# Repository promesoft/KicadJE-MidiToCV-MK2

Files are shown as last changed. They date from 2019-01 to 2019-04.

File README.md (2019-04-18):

# Kicad-MidiToCV
Midi to CV in Eurorack 

# MK2 Design 
## Status - PCB delivered tested
## Initial 
| Stage  | Detail | Status |
| --- | --- | --- |
| create material  | sch/pcb | produced MK2 Rev A  |
| | gerber | Produced MK2 |
| production  | ordered  |  |
|  | produced | yes |
|  | delivered | yes |
## Preliminary validation
| Test  | Detail | Status |
| --- | --- | --- |
| Initial Inspection | conflict between LED on front panel and optional CV7 | OK |
| Initial Technical Test | | OK |
| Initial Product Test |  | OK! |
|  | LED's | OK |
|  | Encoder | OK |
|  | CV1+CV2 | OK |
|  | GATE 1,2,3,4 | OK |
|  | MIDI I/O | OK |

## Secondary validation
| Test  | Detail | Status |
| --- | --- |--- |
| Product Test |  | |
| Quality |  | |
| Long Term Product Test | | Mounted in rack |

## Software 
| Test  | Detail | Status |
| --- | --- |--- |
| Initial SW | copy from MK1 and adjusted | OK! |
| MIDI I/O | UI | |
| MIDI I/O | Filtering and change ch | |
| CV Control | UI |  |
| CV Control | |  |
| LFO Control | UI |  |
| LFO Control | Function |  |

## Errata
 * Physical mounting of the faceplate to holes on the base plate requires other dimensions of the angled mounts. The mounts can be very difficult to get in place due to limited space behind the front PCB.
## Issues and Notes
 * Note - the 4 value LED's are routed across the front board next to analogue and gate signals - so care should be taken when deciding between constant power or PWM control of brightness. The other LED's are not considered as vital as they will normally be lit when config is changed.
 * Consider replacing single row board connector with double row.
 * Physical construction not finalized
### Workarounds

## Base Construction
### Arduino base board 
 - Arduino Nano
 - MIDI IN/OUT connectors
 - CV 1 and CV 2 as Mini Jacks (PJ-301) with variable x2-x3 amplification and 1st order LP filter
 - Gate 1 and Gate 2 as Mini Jacks (PJ-301) 5V
 - Gate 3 and Gate 4 as Mini Jacks (PJ-321) with fixed x2 amplification and sallen-key LP 2nd order filter
 - Board connector 9pin and 11pin from base board to front board
 - 16pin Europower connector
 - Barreljack for 7-12V digital Pwr
 
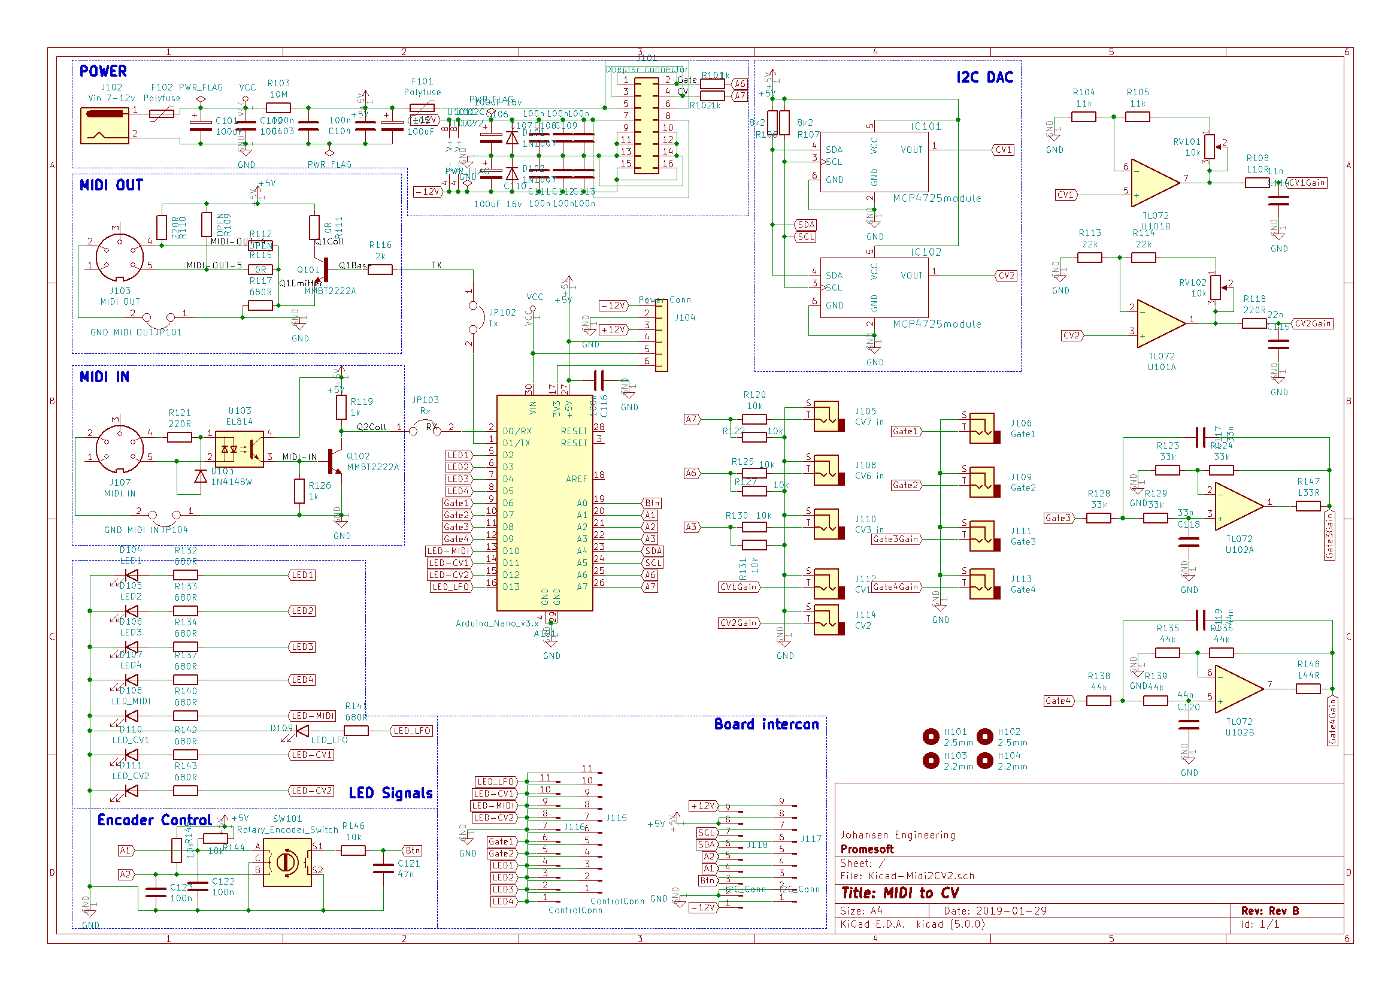
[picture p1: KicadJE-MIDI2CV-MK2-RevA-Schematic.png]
 
 
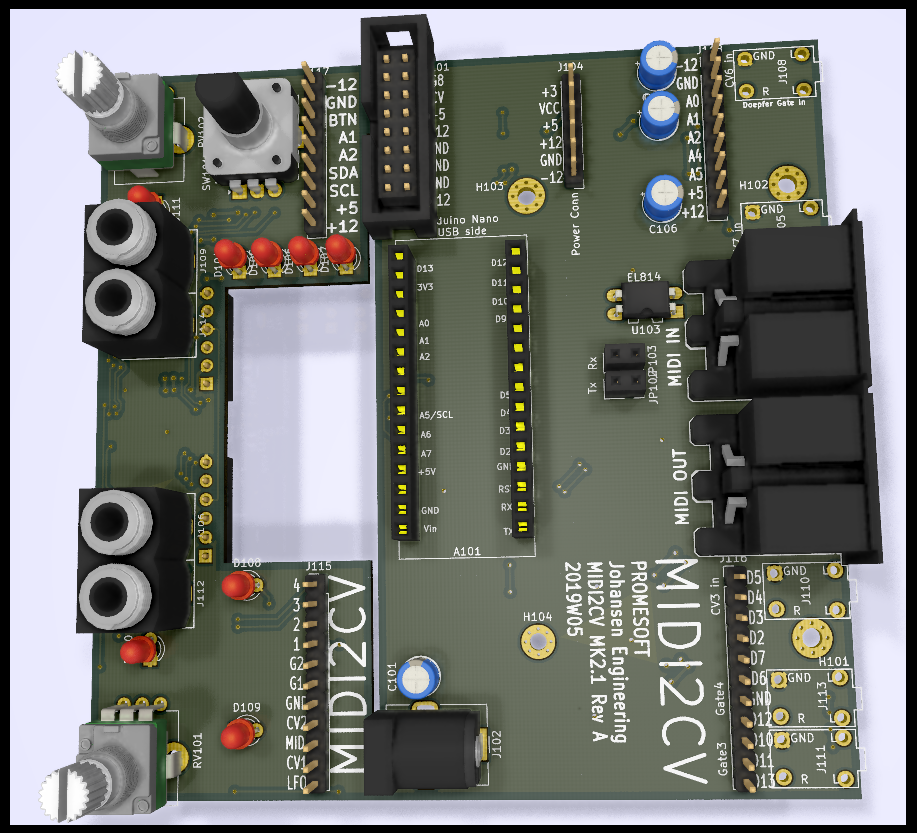
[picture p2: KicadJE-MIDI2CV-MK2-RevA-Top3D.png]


## Vital Components
 - Arduino Nano - where the magic lives (remember to socket it to be able to reprogram it - two jumpers are in place for Rx/Tx so socket may be avoided)
 - Jack connectors: PJ-321 for the base board and PJ-301 for the front board (important for the footprint)
 - ALPS EC-11 Encoder (important for the footprint and 3D alignment)
 - ALPS RV09 horisontal potentiometer (important for the footprint and for variable CV out - can be omitted if this is not needed)
 - MCP4825 module - if chosen (important for CV out function - footprint needs to match)
 - TL072 or similar dual op amp
 
### Mechanical
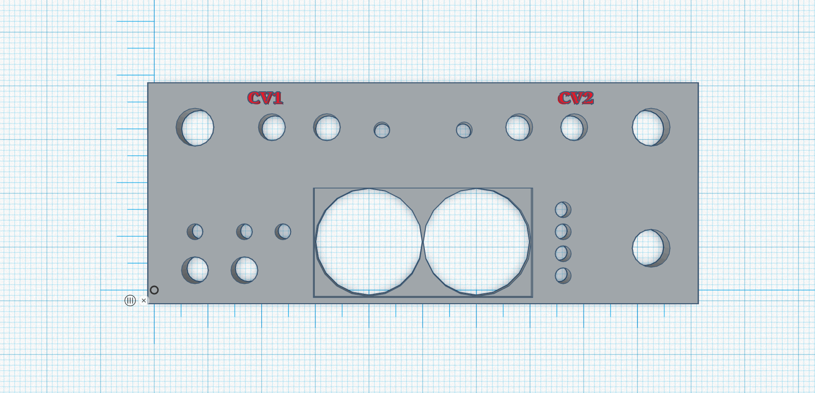
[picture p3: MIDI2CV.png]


The construction is still split in two - but the MK2 design relies on a base board that is 90degrees to the face plate (like the MK1) and a connector board that is 10mm behind the faceplate 90 degrees angle to the base board.

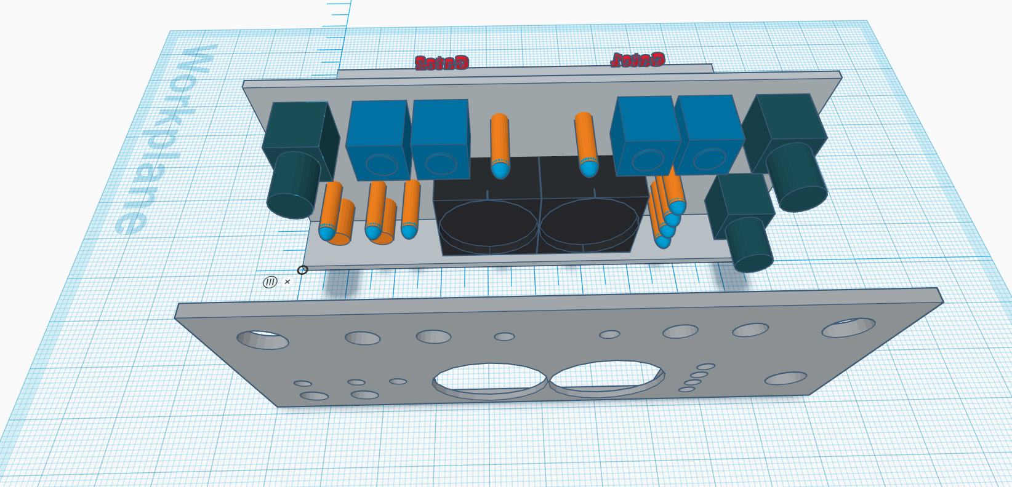
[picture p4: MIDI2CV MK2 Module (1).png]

-----------------------------------------------------

# MK1 Design
## Status - Rev B - Ongoing PCB layout and Sch update

## Status - Rev A Mounted - Midi code in progress
### Issues and Notes
Please note that the PIN1 and PIN2 are GATE. This is note described clearly in http://www.doepfer.de/a100_man/a100t_e.htm and needs to be noted when soldering the IDC header or when cabling if a Pin header has been mounted.
 * The two pots on the breakout board are too close for adding a knob
 * The orientation of the pinheader for the MCP4725 module - if mounted incorrectly the magic smoke disappears
 * 0R could be replaced with SMD jumpers
 * Consider a 200 mA fuse for Vin and 50mA for +5V pwr
 * The mounting hole that is off center is not matching both boards
### Errata
 * Footprint of PJ-321 has too small drill holes (1mm) - major
 * Footprint of PJ-321 is too narrow in the rear end :) - minor issue
 * Midi out circuit is WRONG - Major
### Workarounds
* Midi out not working - PCB workaround mod partially possible  
 * --Remove GND around DIN pin 5 (bottom copper side)
 * --Cut GND track to DIN pin 5 (top copper side)
 * --Remove Q1, R6, R9
 * --Connect 220R THT to base pad on Q1
 * --Connect C and E on Q1
 * --Add GND wire to pin2 of MIDI out DIN
## Physical Construction
 - 100x100mm
 - Separate unit with no alteration
 - Optional split in 2 for eurorack mount mirrored config

## Vital Components
 - Arduino Nano - where the magic lives (remember to socket it to be able to reprogram it)
 - Jack connectors: PJ-321 (important for the footprint)
 - KY-40 Encoder module (important for the pullup, footprint and 3D alignment)
 - MCP4825 module - if chosen (important for CV out function - footprint needs to match)
 If these are chosen the last two CV jacks should be ommitted.
 - MCP4728 chip - if chosen (important for the last 2 CV out)

## MIDI Board Features
### Single board - MIDI I/O and MIDI to CV
The board can be used as is for a prototype development of MIDI to CV
### Split board Eurorack - MIDI I/O and MIDI to CV
The board can be devided in two and combined front to front with spacers for a MIDI to CV eurorack module.
### Base board Eurorack - MIDI I/O
If only MIDI features are required the base board can work without the IO section.

## Generic Board Features
### Split board Options
The main board (with the arduino) has a couple of headers that can be connected to a different interface board using I2C, Analogue Inputs and Digital I/O.
### Non MIDI board
The MIDI components can be omitted if the features does not require MIDI, like an LFO, VCO or ADSR circuit.

## Base Construction
Arduino Nano based Controller and MIDI decoder.


### MIDI In
MIDI In through a PC814 (or optional PC817) Optocoupler and into the RX pin on the Arduino

### Midi Out
Optional expansion

### Gate
Gate pins from Arduino

## CV Out
I2C Dac with 2 options
### I2C Dac - Option 1 - Two Single channel DAC
2x MCP4725 DAC 
### I2C Dac - Option 2 - One 4 channel DAC
1x MCP4728

# RevB

# RevA


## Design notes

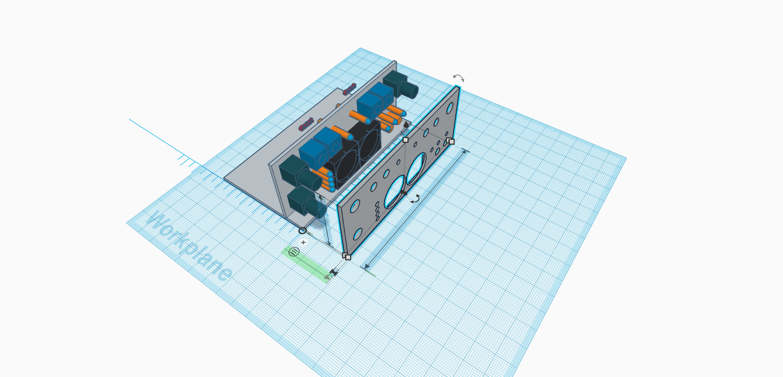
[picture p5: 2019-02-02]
MIDI2CV MK2 Module.png

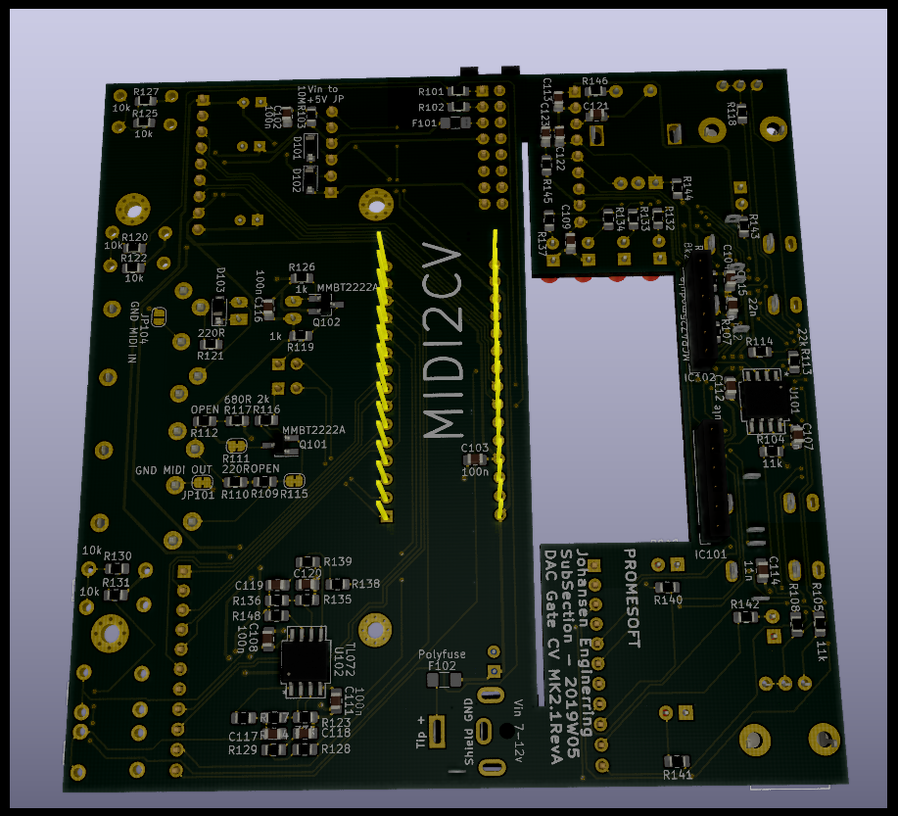
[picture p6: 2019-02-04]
KicadJE-MIDI2CV-MK2-RevA-Bottom3D.png

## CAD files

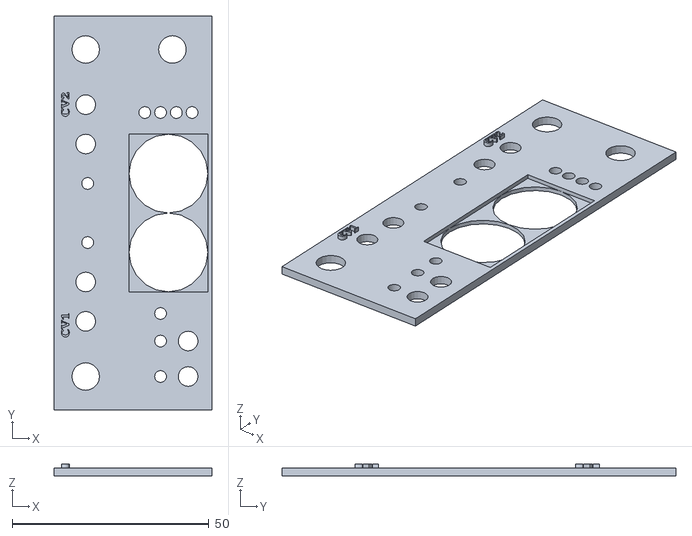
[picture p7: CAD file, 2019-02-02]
MIDI2CV.stl
40.0 x 100.0 x 3.00

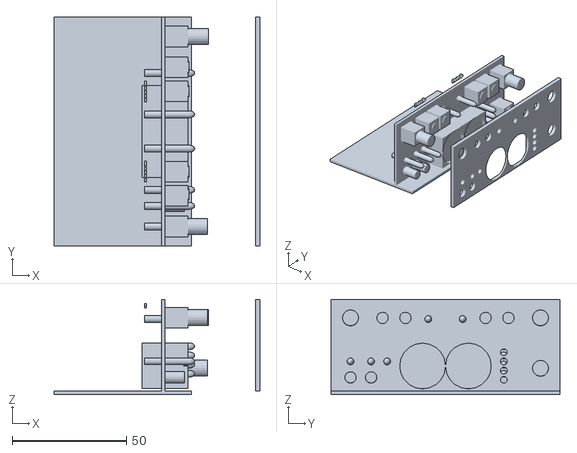
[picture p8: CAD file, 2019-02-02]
MIDI2CV MK2 Module.stl
90.0 x 100.0 x 41.6

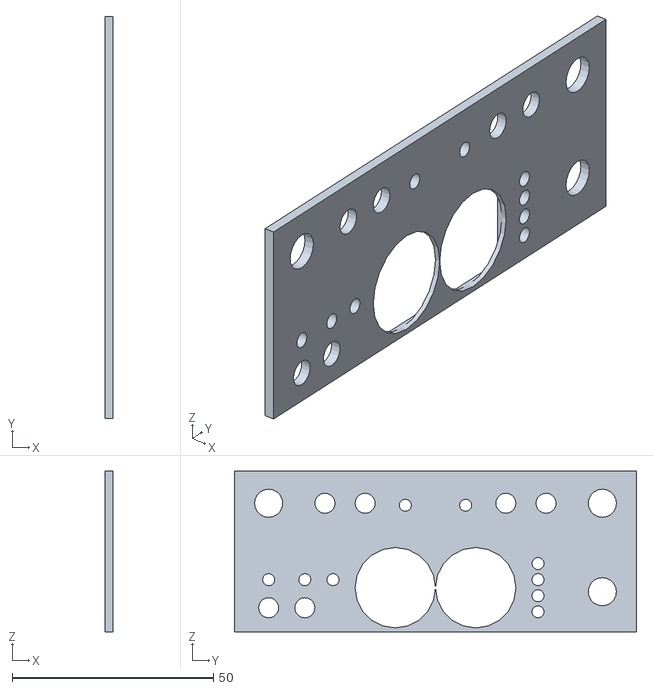
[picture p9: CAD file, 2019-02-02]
MIDI2CV MK2 Module (1).stl
2.00 x 100.0 x 40.0

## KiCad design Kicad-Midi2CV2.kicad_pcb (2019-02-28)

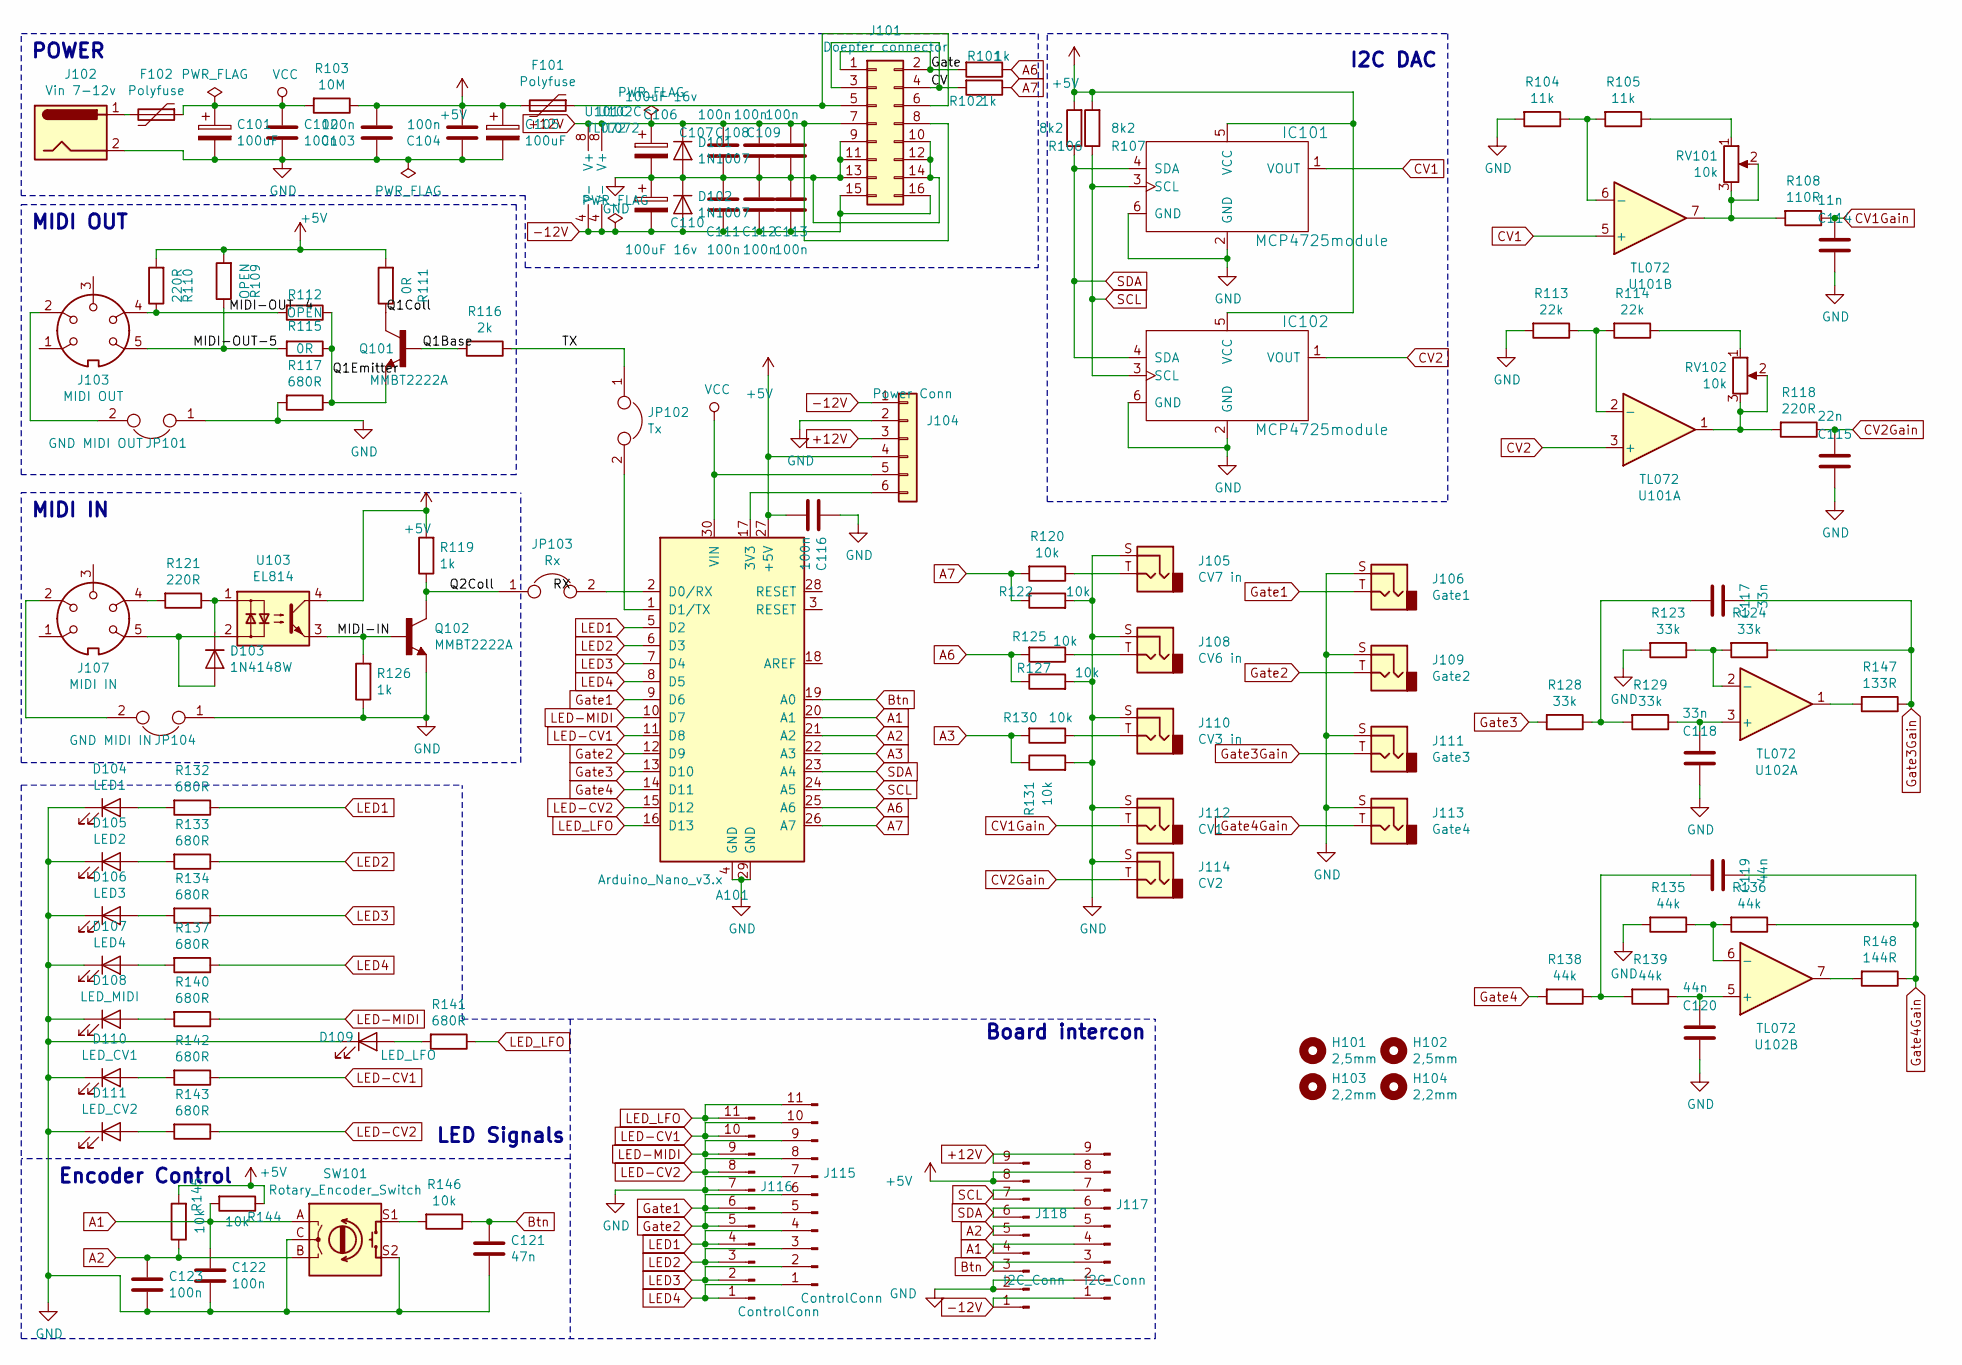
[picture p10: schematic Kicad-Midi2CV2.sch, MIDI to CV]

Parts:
A101: Arduino_Nano_v3.x; Arduino_Nano
C101, C105: 100uF; CP_Radial_D5.0mm_P2.50mm
C102, C103, C104, C107, C108, C109, C111, C112, C113, C116, C122, C123: 100n; C_0805_2012Metric_Pad1.15x1.40mm_HandSolder
C106, C110: 100uF 16v; CP_Radial_D5.0mm_P2.50mm
C114: 11n; C_0805_2012Metric_Pad1.15x1.40mm_HandSolder
C115: 22n; C_0805_2012Metric_Pad1.15x1.40mm_HandSolder
C117, C118: 33n; C_0805_2012Metric_Pad1.15x1.40mm_HandSolder
C119, C120: 44n; C_0805_2012Metric_Pad1.15x1.40mm_HandSolder
C121: 47n; C_0805_2012Metric_Pad1.15x1.40mm_HandSolder
D101, D102: 1N1007; D_SOD-123
D103: 1N4148W; D_SOD-123
D104: LED1; LED_D3.0mm
D105: LED2; LED_D3.0mm
D106: LED3; LED_D3.0mm
D107: LED4; LED_D3.0mm
D108: LED_MIDI; LED_D3.0mm
D109: LED_LFO; LED_D3.0mm
D110: LED_CV1; LED_D3.0mm
D111: LED_CV2; LED_D3.0mm
F101, F102: Polyfuse; Fuse_1206_3216Metric_Pad1.42x1.75mm_HandSolder
H101, H102: 2,5mm; MountingHole_2.5mm_Pad_Via
H103: 2,2mm; MountingHole_2.5mm_Pad_Via
H104: 2,2mm; MountingHole_2.2mm_M2_Pad_Via
IC101, IC102: MCP4725module; PinSocket_1x06_P2.54mm_Vertical
J101: Doepfer connector; PinSocket_2x08_P2.54mm_Vertical
J102: Vin 7-12v; BarrelJack_CUI_PJ-063AH_Horizontal
J103: MIDI OUT; din-5
J104: Power Conn; PinHeader_1x06_P2.54mm_Vertical
J105: CV7 in; AudioJack3StereoNarrow-PJ-321
J106: Gate1; PJ301SM
J107: MIDI IN; din-5
J108: CV6 in; AudioJack3StereoNarrow-PJ-321
J109: Gate2; PJ301SM
J110: CV3 in; AudioJack3StereoNarrow-PJ-321
J111: Gate3; AudioJack3StereoNarrow-PJ-321
J112: CV1; PJ301SM
J113: Gate4; AudioJack3StereoNarrow-PJ-321
J114: CV2; PJ301SM
J115, J116: ControlConn; PinHeader_1x11_P2.54mm_Vertical
J117, J118: I2C_Conn; PinHeader_1x09_P2.54mm_Vertical
JP101: GND MIDI OUT; SolderJumper-2_P1.3mm_Bridged_RoundedPad1.0x1.5mm
JP102: Tx; PinSocket_1x02_P2.54mm_Vertical
JP103: Rx; PinSocket_1x02_P2.54mm_Vertical
JP104: GND MIDI IN; SolderJumper-2_P1.3mm_Open_RoundedPad1.0x1.5mm
Q101, Q102: MMBT2222A; SOT-23_Handsoldering
R101, R102, R119, R126: 1k; R_0805_2012Metric_Pad1.15x1.40mm_HandSolder
R103: 10M; R_0805_2012Metric_Pad1.15x1.40mm_HandSolder
R104, R105: 11k; R_0805_2012Metric_Pad1.15x1.40mm_HandSolder
R106, R107: 8k2; R_0805_2012Metric_Pad1.15x1.40mm_HandSolder
R108: 110R; R_0805_2012Metric_Pad1.15x1.40mm_HandSolder
R109, R112: OPEN; R_0805_2012Metric_Pad1.15x1.40mm_HandSolder
R110, R118, R121: 220R; R_0805_2012Metric_Pad1.15x1.40mm_HandSolder
R111, R115: 0R; SolderJumper-2_P1.3mm_Bridged_RoundedPad1.0x1.5mm
R113, R114: 22k; R_0805_2012Metric_Pad1.15x1.40mm_HandSolder
R116: 2k; R_0805_2012Metric_Pad1.15x1.40mm_HandSolder
R117, R132, R133, R134, R137, R140, R141, R142, R143: 680R; R_0805_2012Metric_Pad1.15x1.40mm_HandSolder
R120, R122, R125, R127, R130, R131, R144, R145, R146: 10k; R_0805_2012Metric_Pad1.15x1.40mm_HandSolder
R123, R124, R128, R129: 33k; R_0805_2012Metric_Pad1.15x1.40mm_HandSolder
R135, R136, R138, R139: 44k; R_0805_2012Metric_Pad1.15x1.40mm_HandSolder
R147: 133R; R_0805_2012Metric_Pad1.15x1.40mm_HandSolder
R148: 144R; R_0805_2012Metric_Pad1.15x1.40mm_HandSolder
RV101, RV102: 10k; Potentiometer_Alps_RK09K_Single_Vertical
SW101: Rotary_Encoder_Switch; RotaryEncoder_Alps_EC11E-Switch_Vertical_H20mm
U101, U102: TL072; AJ_SO-8_5.3x6.2mm_P1.27mm
U103: EL814; DIP-4_W7.62mm_LongPads

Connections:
+5V: A101.27 (+5V), C103.2, C104.2, C105.1, C116.2, F101.2, IC101.5 (VCC), IC102.5 (VCC), J104.4, J117.8, J118.8, R103.1, R106.2, R107.2, R109.2, R110.2, R111.2, R119.2, R144.1, R145.2, U103.4
+12V: C106.1, C107.2, C108.2, C109.2, D101.1 (K), J101.7, J101.8, J104.3, J117.9, J118.9, U101.8 (V+), U102.8 (V+)
-12V: C110.2, C111.1, C112.1, C113.1, D102.2 (A), J101.15, J101.16, J104.1, J117.1, J118.1, U101.4 (V-), U102.4 (V-)
/CV: J101.3, J101.4, R102.2
/Gate: J101.1, J101.2, R101.2
/MIDI-IN: Q102.1 (B), R126.2, U103.3
/MIDI-OUT-4: J103.4, R110.1, R112.2
/MIDI-OUT-5: J103.5, R109.1, R115.2
/Q1Base: Q101.1 (B), R116.2
/Q1Coll: Q101.3 (C), R111.1
/Q1Emitter: Q101.2 (E), R112.1, R115.1, R117.1
/Q2Coll: JP103.1, Q102.3 (C), R119.1
/TX: JP102.1, R116.1
A1: A101.20 (A1), C122.1, J117.4, J118.4, R144.2, SW101.A
A2: A101.21 (A2), C123.1, J117.5, J118.5, R145.1, SW101.B
A3: A101.22 (A3), R130.2, R131.1
A6: A101.25 (A6), R101.1, R125.2, R127.1
A7: A101.26 (A7), R102.1, R120.2, R122.1
Btn: A101.19 (A0), C121.1, J117.3, J118.3, R146.1
CV1: IC101.1 (VOUT), U101.5 (+)
CV1Gain: C114.1, J112.T, R108.1
CV2: IC102.1 (VOUT), U101.3 (+)
CV2Gain: C115.1, J114.T, R118.1
GND: A101.4 (GND), A101.29 (GND), C101.2, C102.2, C103.1, C104.1, C105.2, C106.2, C107.1, C108.1, C109.1, C110.1, C111.2, C112.2, C113.2, C114.2, C115.2, C116.1, C118.2, C120.2, C121.2, C122.2, C123.2, D101.2 (A), D102.1 (K), D104.1 (K), D105.1 (K), D106.1 (K), D107.1 (K), D108.1 (K), D109.1 (K), D110.1 (K), D111.1 (K), IC101.2 (GND), IC101.6 (GND), IC102.2 (GND), IC102.6 (GND), J101.9, J101.10, J101.11, J101.12, J101.13, J101.14, J102.2, J104.2, J105.S, J106.S, J108.S, J109.S, J110.S, J111.S, J112.S, J113.S, J114.S, J115.7, J116.7, J117.2, J118.2, JP101.1, JP104.1, Q102.2 (E), R104.2, R113.2, R117.2, R122.2, R123.2, R126.1, R127.2, R131.2, R135.2, SW101.C, SW101.S2
Gate1: A101.9 (D6), J106.T, J115.6, J116.6
Gate2: A101.12 (D9), J109.T, J115.5, J116.5
Gate3: A101.13 (D10), R128.2
Gate3Gain: C117.1, J111.T, R124.1, R147.1
Gate4: A101.14 (D11), R138.2
Gate4Gain: C119.1, J113.T, R136.1, R148.1
LED1: A101.5 (D2), J115.4, J116.4, R132.1
LED2: A101.6 (D3), J115.3, J116.3, R133.1
LED3: A101.7 (D4), J115.2, J116.2, R134.1
LED4: A101.8 (D5), J115.1, J116.1, R137.1
LED-CV1: A101.11 (D8), J115.10, J116.10, R142.1
LED-CV2: A101.15 (D12), J115.8, J116.8, R143.1
LED-MIDI: A101.10 (D7), J115.9, J116.9, R140.1
LED_LFO: A101.16 (D13), J115.11, J116.11, R141.1
unnamed: A101.1 (D1/TX), JP102.2
unnamed: A101.2 (D0/RX), JP103.2
unnamed: A101.17 (3V3), J104.6
unnamed: C117.2, R128.1, R129.2
unnamed: C118.1, R129.1, U102.3 (+)
unnamed: C119.2, R138.1, R139.2
unnamed: C120.1, R139.1, U102.5 (+)
unnamed: D103.1 (K), R121.1, U103.1
unnamed: D103.2 (A), J107.5, U103.2
unnamed: D104.2 (A), R132.2
unnamed: D105.2 (A), R133.2
unnamed: D106.2 (A), R134.2
unnamed: D107.2 (A), R137.2
unnamed: D108.2 (A), R140.2
unnamed: D109.2 (A), R141.2
unnamed: D110.2 (A), R142.2
unnamed: D111.2 (A), R143.2
unnamed: F101.1, J101.5, J101.6
unnamed: F102.2, J102.1
unnamed: J103.2, JP101.2
unnamed: J105.T, R120.1
unnamed: J107.2, JP104.2
unnamed: J107.4, R121.2
unnamed: J108.T, R125.1
unnamed: J110.T, R130.1
unnamed: R104.1, R105.2, U101.6 (-)
unnamed: R105.1, RV101.1
unnamed: R108.2, RV101.2, RV101.3, U101.7
unnamed: R113.1, R114.2, U101.2 (-)
unnamed: R114.1, RV102.1
unnamed: R118.2, RV102.2, RV102.3, U101.1
unnamed: R123.1, R124.2, U102.2 (-)
unnamed: R135.1, R136.2, U102.6 (-)
unnamed: R146.2, SW101.S1
unnamed: R147.2, U102.1
unnamed: R148.2, U102.7
SCL: A101.24 (A5), IC101.3 (SCL), IC102.3 (SCL), J117.7, J118.7, R107.1
SDA: A101.23 (A4), IC101.4 (SDA), IC102.4 (SDA), J117.6, J118.6, R106.1
VCC: A101.30 (VIN), C101.1, C102.1, F102.1, J104.5, R103.2

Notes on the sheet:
MIDI IN
LED Signals
Encoder Control
I2C DAC
POWER
MIDI OUT
Board intercon

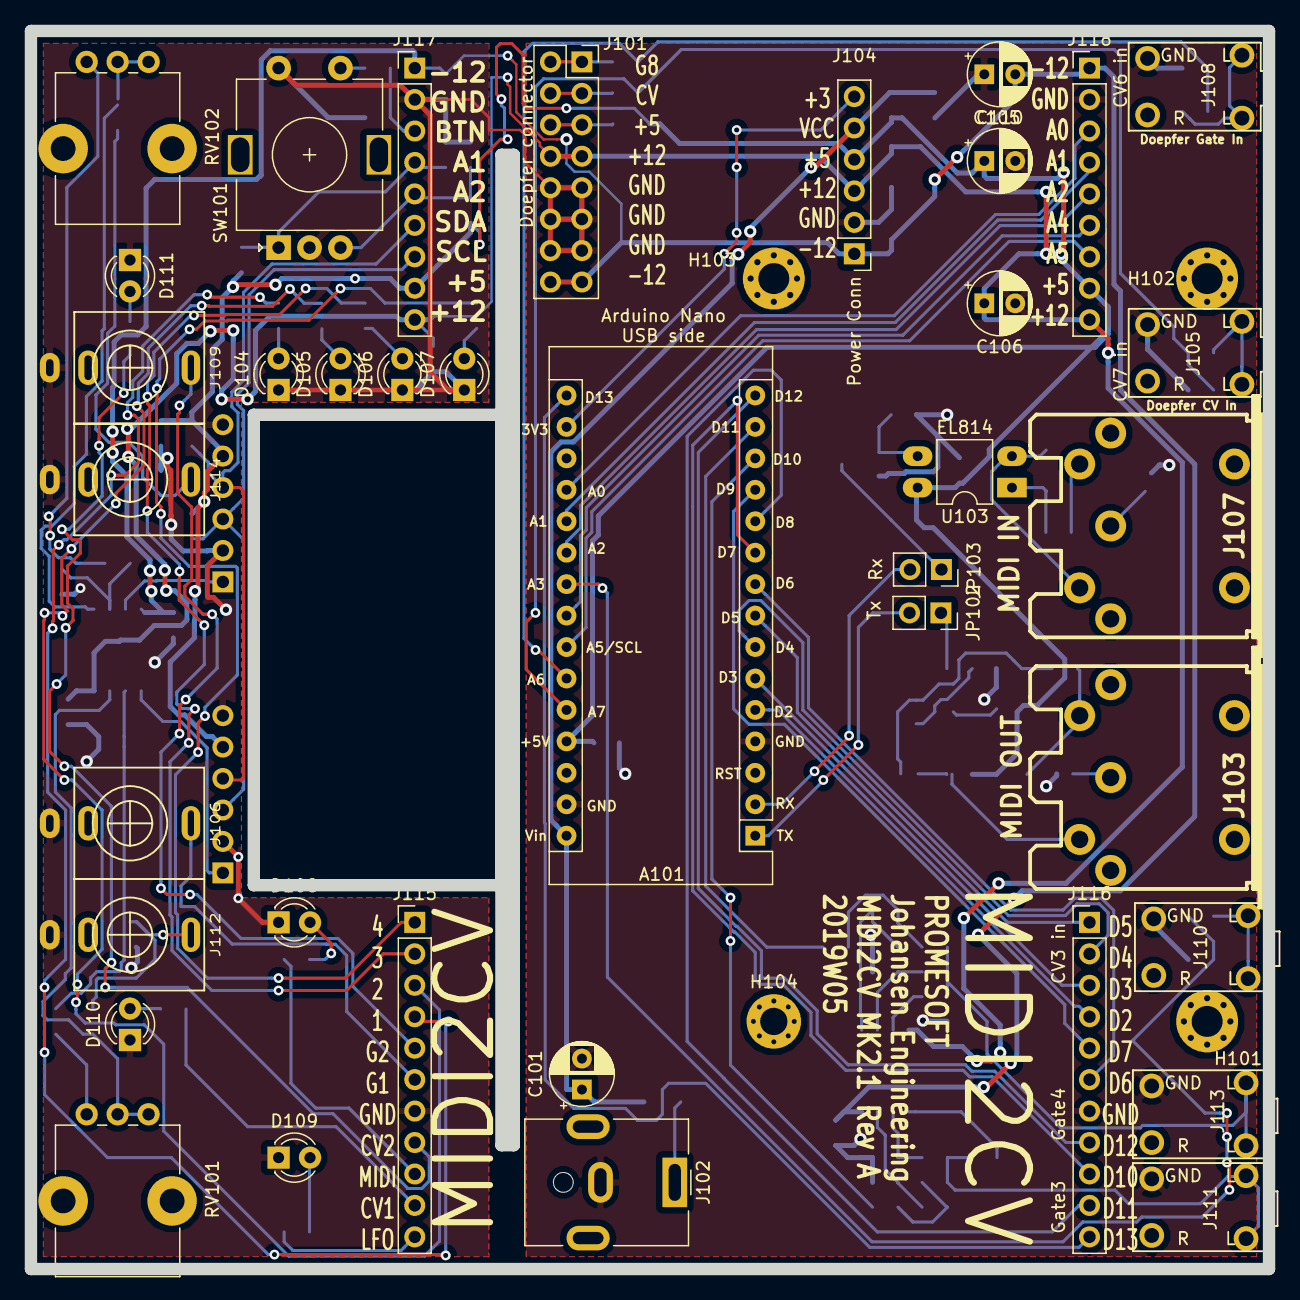
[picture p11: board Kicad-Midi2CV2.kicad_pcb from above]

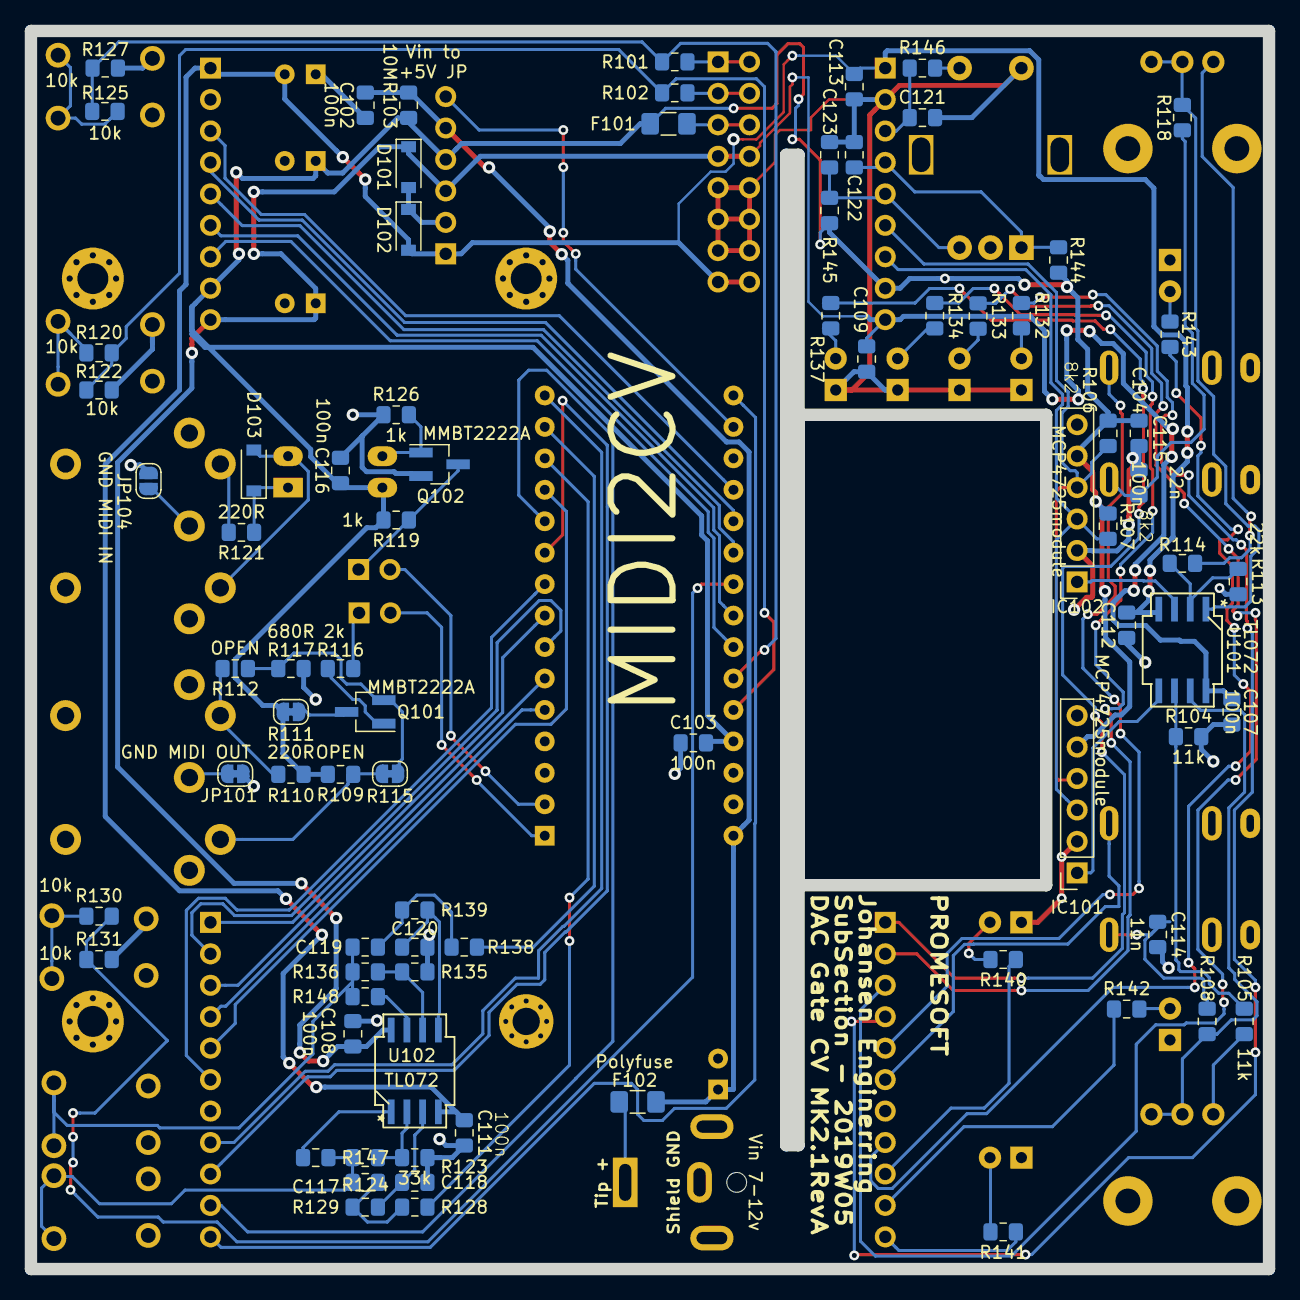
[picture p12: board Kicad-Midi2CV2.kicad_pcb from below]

Board: 2 copper layers, 100.0 x 100.0 mm, 121 parts (80 on the bottom side), 77 nets.

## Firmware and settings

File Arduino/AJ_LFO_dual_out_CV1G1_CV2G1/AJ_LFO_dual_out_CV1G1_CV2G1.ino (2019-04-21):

/* 
 * Wavetable LFO inspiration: 
 * https://www.muffwiggler.com/forum/viewtopic.php?t=169706&sid=4b0d7d4af599d0df3e7b6fc29ece21b8 
 *  
 */ 

#include "wavetable.h";
//#include "globals.h";
#include "midi.h";


/* =====================================================
==============INIT DATA STRUCTURES======================
======================================================*/  
void setupDataStruct(){
   for (int i=0; i <= 3; i++){
     for (int j=0; j <= 3; j++){
      LEDData[i][j]=false;
     }
     MIDI_CH[i] = EEPROM.read(i);
     if (MIDI_CH[i] > 15) MIDI_CH[i] = 0;
      updateLEDValue(MIDI_CH[i], i);
      encoder[i] = MIDI_CH[i] << 2;
   }
}
/* =====================================================
==============SETUP=====================================
======================================================*/  
void setup() {  
  Serial.begin(38400);
  Serial.println();
  Serial.println("");
  Serial.println(F(__FILE__));
  Serial.print(F("Build date: "));
  Serial.println(F(__DATE__));
  delay(50);  
  setupDataStruct();
  
/* ===========Encoder Setup=============================*/
  pinMode(SWpin, INPUT);
  pinMode(Apin, INPUT);
  pinMode(Bpin, INPUT);
  // Enable internal pull-up resistors
  digitalWrite(SWpin, HIGH);
  digitalWrite(Apin, HIGH);
  digitalWrite(Bpin, HIGH);

/* ===========LED Setup=================================*/
  pinMode(LED1, OUTPUT);
  pinMode(LED2, OUTPUT);
  pinMode(LED3, OUTPUT);
  pinMode(LED4, OUTPUT);
  pinMode(LED_MIDI, OUTPUT);
  pinMode(LED_CV1, OUTPUT);
  pinMode(LED_CV2, OUTPUT);
  pinMode(LED_LFO, OUTPUT);
    
  digitalWrite(LED1, HIGH);
  digitalWrite(LED2, HIGH);
  digitalWrite(LED3, HIGH);
  digitalWrite(LED4, HIGH);
  digitalWrite(LED_MIDI, HIGH);
  digitalWrite(LED_CV1, HIGH);
  digitalWrite(LED_CV2, HIGH);
  digitalWrite(LED_LFO, HIGH);
  delay(150);

  updateLED();

/* =========Saw wave for table 1 =======================*/
/*  for(int i=0; i<256; i++) {                                  // Precalculates a simple Tri-Wavetable in the first wavetable. Delete these 2 for-loops if you have filled up your wavetables 
    waveTable[1][i]=i; 
    }*/   
/* =========Triangle wave for table 2===================*/
/*  for(int i=0; i<128; i++) {                                  // Precalculates a simple Tri-Wavetable in the first wavetable. Delete these 2 for-loops if you have filled up your wavetables 
    waveTable[2][i]=i*2; 
    } 
  for(int i=0; i<128; i++)  { 
    waveTable[2][i+128]=256-i*2; 
  } 
  waveTable[2][128]=255;*/
/* =========Step 8 wave table 3=========================*/
/*  for(int i=0; i<256; i++) {                                  // Precalculates a simple Tri-Wavetable in the first wavetable. Delete these 2 for-loops if you have filled up your wavetables 
    waveTable[3][i]=(i&0b11100000); 
    }*/ 
/* =========Setup LFO Output pins=======================*/
  pinMode(PWM1, OUTPUT);                                           // Sets Pin PWM1 PWM-Output 
  pinMode(PWM2, OUTPUT);                                           // Sets Pin PWM2 PWM-Output 
//  pinMode(Square, OUTPUT);                                          // Pin as LED for Tempo and as a square-LFO 
//  pinMode(InvSquare, OUTPUT);                                          // Pin as LED for Tempo and as a inverted square-LFO 
/* =========Setup Gate Output pins======================*/
  pinMode(Gate1, OUTPUT);                                           // Sets Pin PWM1 PWM-Output 
  pinMode(Gate2, OUTPUT);                                           // Sets Pin PWM2 PWM-Output 
  
/* =========Enable interrupt on A0,1,2==================*/
  // 1. PCIE1: Pin Change Interrupt Enable 1
  PCICR =  0b00000010; 
  // Enable Pin Change Interrupt for A0, A1, A2
  PCMSK1 = 0b00000111; 

//Safety before MIDI takes over so the arduino can be reprogrammed
  delay(800); 
/* =====================================================*/
  setupMidi();
} 

/* =====================================================
==============MAIN LOOP=================================
======================================================*/  
void loop() { 
  checkencoder();                  //Check encoder and update values

  updateLED();                     //LED on for active state    
  midiRead();
  updateLEDValue(MIDI_CH[0], 0); //Update current midi chan for state 0
  clearLED();                      //LED off (dim light)

  updatewave();
}

/* =====================================================
==============Update LED's based on LED Values==========
======================================================*/ 
char getWaveSample(unsigned int PWMshape){
    switch (PWMshape) {
      case 1:
        PWMdata = tableStep;
        // Saw wave for shape 1
        break;
      case 2:
        PWMdata = 256-tableStep;
        // Inv Saw wave for shape 2
        break;
      case 3:
        //Triangle wave for shape 3
        PWMdata = tableStep * 2;
        if (tableStep > 127) PWMdata = 256-(2*(tableStep-127)); 
        break;
      case 4: // Step 4
        PWMdata = (tableStep&0b11000000)+64;
        break;
      case 5: // Step 8
        PWMdata = (tableStep&0b11100000)+32;
        break;
      case 6: // Step 16
        PWMdata = (tableStep&0b11110000)+16;
        break;
      case 7: // Step 32
        PWMdata = (tableStep&0b11111000)+8;
        break;
      case 8: // Step 4 + noise
        PWMdata = random(120) * (tableStep>>6);
        break;
      case 9: // Step 8 + noise
        PWMdata = random(60) * (tableStep>>5);
        break;
      case 10: // noise
        PWMdata = random(255);
        break;
      case 11: // noise
        PWMdata = random(128) + tableStep;
        break;
      case 12: // ramp and noise
        if (tableStep < 127 ) {
          PWMdata = 2 * tableStep;
        }
        else {
          PWMdata = random(255);
        }
        break;
      case 13: // half ramp
        if (tableStep < 127 ) {
          PWMdata = 2 * tableStep;
        }
        else {
          PWMdata = 0;
        }
        break;
      case 14: // 25% duty cycle
        if (tableStep < 63 ) {
          PWMdata = 255;
        }
        else {
          PWMdata = 0;
        }
        break;
      case 15: // pulse 6% duty cycle
        PWMdata = 0;
        if (tableStep < 64) {
          PWMdata = 255;
        }
        if (tableStep > 128) {
          if (tableStep < 192) {
            PWMdata = 255;
          }
        }
        break;
      default:
        // Sine wave for shape 0
        PWMdata = waveTable[tableStep];
        break;
    }
    return PWMdata;
}
/* =====================================================
==============Update Wave data pointer==================
======================================================*/ 
void updatewave(){
  if ( millis() >= (lastwaveupdate+delayTime) ){
    lastwaveupdate = millis();
    tableStep++;                                                // Jumps to the next step. 
                                                                /* tableStep is an 8-Bit unsigned integer, 
                                                                so it can only store a value between 0 and 255 and will 
                                                                automatically "overflow" and go back to 0 when it gets 
                                                                bigger than 255, which is the lenght of the lookup table. 
                                                                 */ 
  /*  Serial.print(F("Delay time: "));
    Serial.print(MIDI_CH[3]<<1);
    Serial.println(F(" "));*/
    delayTime =  32 - (MIDI_CH[3]<<1);                                 // values from 0 to 15 shifted up 1 
                                                                // multiplied by 2 as delay from sample to sample 
  /* ===========Update Square Output======================*/
/*    if(tableStep<128) {                                           // Turn LED on for first half of the cycle, indicate Tempo 
      digitalWrite(Square, HIGH); 
      digitalWrite(InvSquare, LOW); 
    } 
    else {                                                        // Turn it off for the second half 
      digitalWrite(Square, LOW); 
      digitalWrite(InvSquare, HIGH); 
    } */
  /* ===========Update PWM1 Output========================*/
    PWMdata = getWaveSample(MIDI_CH[2]);

  //  analogWrite(PWM1, waveTable[PWMshape1][tableStep]);              // Writes the value at the current step in the table to Pin 5 as PWM-Signal.  
    analogWrite(PWM1, PWMdata);
  
  /* ===========Update PWM2 Output========================*/
    PWMdata = getWaveSample(0b00001111&(MIDI_CH[2]+4));
  //  analogWrite(PWM2, waveTable[PWMshape2][tableStep]);              // Writes the value at the current step in the table to Pin 5 as PWM-Signal.  
     analogWrite(PWM2, PWMdata);
  }
}

/* =====================================================
==============Check encoder interrupt===================
======================================================*/ 
void checkencoder(){
  if (left){
    left = false;
    if (encoder[state] != 0) encoder[state]--; // Decrement if not 0
    if (state < 4) {
      if(((MIDI_CH[state]=encoder[state] >> 2) == 0) && state == 2) MIDI_CH[state]=16;
      updateLEDValue(MIDI_CH[state], state);
      EEPROM.write(state, MIDI_CH[state]);
    }
  }
  if (right){
    right = false;
    if (encoder[state] < 0x3f) encoder[state]++;
    if (state < 4) {
      MIDI_CH[state]=encoder[state] >> 2;
      updateLEDValue(MIDI_CH[state], state);
      EEPROM.write(state, MIDI_CH[state]);
    }
  }
  if (button){
    button = false;    
    buttoncnt++;
    buttoncnt = buttoncnt & B00000111;
    state = buttoncnt >> 1;
    }
}
/* =====================================================
==============Update LED Values based on input==========
======================================================*/ 
void updateLEDValue(unsigned int nibble,unsigned int updstate)
{
  if (nibble >= 0x10) nibble = 0x0f;
  else (nibble = nibble & 0x0f);
  if (nibble & 0x01){
//    LED1Data = true;
    LEDData[updstate][0] = true;
  }
  else {
//    LED1Data = false;
    LEDData[updstate][0] = false;
  }
  if (nibble & 0x02){
//    LED2Data = true;
    LEDData[updstate][1] = true;
  }
  else {
//    LED2Data = false;
    LEDData[updstate][1] = false;
  }
  if (nibble & 0x04){
//    LED3Data = true;
    LEDData[updstate][2] = true;
  }
  else {
//    LED3Data = false;
    LEDData[updstate][2] = false;
  }
  if (nibble & 0x08){
//    LED4Data = true;
    LEDData[updstate][3] = true;
  }
  else {
//    LED4Data = false;
    LEDData[updstate][3] = false;
  }

}
/* =====================================================
==============Update LED's based on LED Values==========
======================================================*/ 
void updateLED(){
  boolean blinkstate = byte(millis() >> 9) & CV2State;
  digitalWrite(LED1, LEDData[state][0]);
  digitalWrite(LED2, LEDData[state][1]);
  digitalWrite(LED3, LEDData[state][2]);
  digitalWrite(LED4, LEDData[state][3]);
  delay(1);
  digitalWrite(LED_CV1, state == CV1State);
  digitalWrite(LED_CV2, state == CV2State);
  digitalWrite(LED_LFO, state == LFOState);
  digitalWrite(LED_LFO, (state == SpeedState && blinkstate));
  digitalWrite(LED_MIDI, state == MIDIState);
}

void clearLED(){
  digitalWrite(LED1, LOW);
  digitalWrite(LED2, LOW);
  digitalWrite(LED3, LOW);
  digitalWrite(LED4, LOW);
  digitalWrite(LED_MIDI, LOW);
  digitalWrite(LED_CV1, LOW);
  digitalWrite(LED_CV2, LOW);
  digitalWrite(LED_LFO, LOW);
}

/* =====================================================
==============Encoder change interrupt==================
======================================================*/  

ISR (PCINT1_vect) {
// If interrupt is triggered by the button
  boolean SW_val = digitalRead(SWpin);
  if (SW_val != SW_old) {
    SW_old = SW_val;
    button = true;}

// Else if interrupt is triggered by encoder signals
  else {
    
    // Read A and B signals
    boolean A_val = digitalRead(Apin);
    if (A_val != A_old) {
      A_old = A_val;
      if (A_val^B_old) {
        right = true;
      }
      else {
        left = true;
      }
    }
    else {
      boolean B_val = digitalRead(Bpin);
      B_old = B_val;
      if (A_val^B_val) {
        left = true;
      }
      else {
        right = true;
      }
    }
  }
}

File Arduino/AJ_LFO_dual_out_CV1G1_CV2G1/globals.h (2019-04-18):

#include <EEPROM.h>
#include <Adafruit_MCP4725.h>
/* -----------------------------------------------
 *  GLOBAL DEFINES
 *  
 *  
 *  HW PLATFORM = MIDI2CV MK2.1 Rev A 
 *  2019W05 Johansen Engineering 
 *  -----------------------------------------------
 */
//OVERRIDE PINS FOR LFO
#define PWM1 10 // Sets Pin PWM1 PWM-Output = Gate 3
#define PWM2 11 // Sets Pin PWM2 PWM-Output = Gate 4

//OVERRIDE PIN FOR SQUARE LFO
//#define Square 9    //  Pin as LED for Tempo LED and as a square-LFO 
//#define InvSquare 6 //  Pin as LED for Tempo LED and as a inverted square-LFO 

#define SWpin A0 //add 100nF to GND for debounce 
#define Apin A1  //add 100nF to GND for debounce
#define Bpin A2  //add 100nF to GND for debounce
#define CV3in A3 // Base board
#define SDA A4   // Addon board
#define SCL A5   // Addon board
#define CV6in A6 // Doepfer Gate in + Base board
#define CV7in A7 // Doepfer CV in + Base board
#define Gate1 6  //  Addon board G1
#define Gate2 9  //  Addon board G2 

#define LED1 2
#define LED2 3
#define LED3 4
#define LED4 5
#define LED_MIDI 7
#define LED_CV1 8
#define LED_CV2 12
#define LED_LFO 13
#define CV1State B00000000
#define CV2State B00000001
#define LFOState B00000010
#define SpeedState B00000011
#define MIDIState B00000100

#define Gate1 6 // Addon board
#define Gate2 9 // Addon board
#define Gate3 10 // Base board
#define Gate4 11 // Base board

//#define RDY-BSY 12
//#define LDAC 13

#define MCP4725_ADDR 0x60   
#define MCP4725_ADDR2 0x61   
/* -----------------------------------------------
 *  GLOBAL VAR
 * -----------------------------------------------
 */
boolean A_old=0, B_old=1, SW_old=0;
boolean left = false, right = false, button = false;

//Structure for keeping MIDI CH data for LED
boolean LEDData[4][4]; //(see state)

boolean LEDSelData = false, LEDSel2Data = false; 
unsigned int encoder[4], buttoncnt = 0;
unsigned int state = 0; 
//For MIDI In/Out/CV - State 00 = MidiDataInChannel - 01 = MIDI CH in select - 10 = MIDI CH OUT select - 11 = MIDI CH 2 CV select
//For MIDI In/CV/LFO - State 00 = MIDI CH 1 CV select - 01 = MIDI CH 2 CV select - 10 = LFO Waveform - 11 = LFO Speed - 100 = MIDI OUT select

//byte midi_channel=4;
//Structure for keeping MIDI CH data for processing
//With LFO state 0 and 1 are reserved for CV MIDI channels
//With LFO state 2 and 3 are reserved for the LFO settings
byte MIDI_CH[4]; //(see state above)
byte lastpitch0 = 0, lastpitch1 = 0;  // for keeping the last on pitch

unsigned long lastwaveupdate = 0; // LFO millis timer between samples
//unsigned int PWMshape = 0;
unsigned int delayTime = 4; 
uint8_t tableStep = 0;
uint8_t PWMdata = 0;

/* -----------------------------------------------
 *  MIDI2CV VAR
 * -----------------------------------------------
 */
Adafruit_MCP4725 dac;
Adafruit_MCP4725 dac2;
 
int pitches[61] = 
{
     0,   70,  142,  214,  286,  358,  419,  500, 
   571,  642,  713,  786,  860,  933, 1006, 1080, 
  1153, 1226, 1299, 1372, 1445, 1518, 1591, 1664, 
  1737, 1808, 1880, 1952, 2024, 2096, 2168, 2240,
  2310, 2380, 2452, 2525, 2600, 2670, 2740, 2810,
  2880, 2950, 3020, 3090, 3160, 3230, 3300, 3370,
  3440, 3510, 3580, 3650, 3720, 3790, 3860, 3930,
  4000, 4070
};

/* -----------------------------------------------
 *  PROTOTYPES
 * -----------------------------------------------
 */
void MyHandleNoteOn(byte channel, byte pitch, byte velocity);
void MyHandleNoteOff(byte channel, byte pitch, byte velocity);

/*void checkencoder();
//void updateLEDValue(unsigned int nibble,unsigned int updstate);
void updateLED();
void clearLED();
*/

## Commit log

2019-01-31 Project copied from MK1
    [Kicad-Midi2CV.kicad_pcb, Kicad-Midi2CV.sch]
2019-01-31 Schematic updated to MK2
    [Kicad-Midi2CV2.kicad_pcb, Kicad-Midi2CV2.sch]
2019-02-02 Kicad faliure - unknown state
    [Kicad-Midi2CV2.sch]
2019-02-02 Footprints and MIDI out
    [Kicad-Midi2CV2.sch]
2019-02-02 3D Models
    [MIDI2CV MK2 Module (1).stl, MIDI2CV MK2 Module.stl, MIDI2CV.stl]
2019-02-03 MIDI out simplified #1
    [Kicad-Midi2CV2.sch]
2019-02-03 Initial PCB Layout MK2 - incomplete
    [Kicad-Midi2CV2.kicad_pcb, _saved_Kicad-Midi2CV2.sch]
2019-02-03 Footprint replace in sch, netlist and PCB
    [Kicad-Midi2CV2.kicad_pcb, Kicad-Midi2CV2.sch, _saved_Kicad-Midi2CV2.sch]
2019-02-03 Footprints and LED labels
    [Kicad-Midi2CV2.kicad_pcb, Kicad-Midi2CV2.sch]
2019-02-03 Jumper fixes
    [Kicad-Midi2CV2.sch]
2019-02-03 Sch and PCB advancements
    [Kicad-Midi2CV2.kicad_pcb, Kicad-Midi2CV2.sch]
2019-02-03 RC output on CV
    [Kicad-Midi2CV2.kicad_pcb, Kicad-Midi2CV2.sch]
2019-02-03 Component replacement
    [Kicad-Midi2CV2.kicad_pcb, Kicad-Midi2CV2.sch]
2019-02-03 front routed....
    [Kicad-Midi2CV2.kicad_pcb]
2019-02-04 SCH added Rout for Gate3 and Gate4 Op Amp
    [_saved_Kicad-Midi2CV2.sch]
2019-02-04 Initial PCB finished - no DRC
    [Kicad-Midi2CV2.kicad_pcb, Kicad-Midi2CV2.sch, _saved_Kicad-Midi2CV2.sch]
2019-02-04 GND plane
    [Kicad-Midi2CV2.kicad_pcb]
2019-02-04 Component text on PCB
    [Kicad-Midi2CV2.kicad_pcb]
2019-02-04 Gerber RevA
    [Kicad-Midi2CV2-B.Cu.gbr, Kicad-Midi2CV2-B.Mask.gbr, Kicad-Midi2CV2-B.Paste.gbr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]
2019-02-04 gerber w extra pwr and zip - RevA
    [Kicad-Midi2CV2-B.Cu.gbr, Kicad-Midi2CV2-B.Mask.gbr, Kicad-Midi2CV2-B.Paste.gbr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]
2019-02-05 BOM and A2 gerber (front silk minor)
    [Kicad-Midi2CV2-B.Cu.gbr, Kicad-Midi2CV2-B.Mask.gbr, Kicad-Midi2CV2-B.Paste.gbr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]
2019-02-28 MOVED PINS AROUND ON ARDUINO
    [Kicad-Midi2CV2.sch]
2019-02-28 pinout changed in PCB
    [Kicad-Midi2CV2.kicad_pcb]
2019-02-28 modify wiring - make new gerber
    [Kicad-Midi2CV2-B.Cu.gbr, Kicad-Midi2CV2-B.Mask.gbr, Kicad-Midi2CV2-B.Paste.gbr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]
2019-03-23 Arduino initiated
2019-03-23 Tracking I2C missing audio
    [globals.h, midi.h]
2019-04-18 Arduino - new project
2019-04-18 Remember last pitch before note off (monophonic)
